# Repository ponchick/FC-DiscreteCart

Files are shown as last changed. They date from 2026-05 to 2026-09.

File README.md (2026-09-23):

# FC-DiscreteCart

Discrete logic Famicom / Dendy cartridge PCB.

The following board types are supported:  
NROM, CNROM, GNROM, BNROM, AMROM, ANROM, AOROM, UNROM, UOROM.

Russian version: [`README.ru.md`](README.ru.md)

## Jumper configuration

All jumpers except JP1 are set according to the table below.  
JP1 (VRAM_A10) selects PPU nametable mirroring — see the note after the table.

| ROM type | U1* type | U2 type | U3 74161 | U4 7432 | U5 7402 | JP1 VRAM_A10 | JP2 PRG_OE | JP3 CHR_PIN26 | JP4 CHR_PIN27 | JP5 161_Q2 | JP6 161_Q3 | JP7 PRG_A14 | JP8 PRG_A15 | JP9 PRG_A15 | JP10 PRG_A16 | JP11 PRG_A16 | JP12 PRG_A17 |
| :--- | :--- | :--- | --- | --- | --- | --- | --- | --- | --- | --- | --- | --- | --- | --- | --- | --- | --- |
| NROM | ROM 16kB/32kB | ROM 8kB | ✗ | ✗ | ✗ | V/H\*\* | bridge 2–3 | bridge 2–3 | bridge 2–4 | do not bridge | do not bridge | bridge 1–2 | do not bridge | bridge 2–3 | do not bridge | bridge 2–3 | bridge 2–4 |
| CNROM | ROM 16kB/32kB | ROM 32kB | ✓ | ✗ | ✗ | V/H\*\* | bridge 2–3 | bridge 1–2 | bridge 1–2 | bridge 1–2 | bridge 2–4 | bridge 1–2 | do not bridge | bridge 2–3 | do not bridge | bridge 2–3 | bridge 2–4 |
| GNROM | ROM 128kB | ROM 32kB | ✓ | ✗ | ✗ | V/H\*\* | bridge 2–3 | bridge 1–2 | bridge 1–2 | bridge 1–2 | bridge 2–4 | bridge 1–2 | do not bridge | bridge 1–2 | do not bridge | bridge 1–2 | bridge 2–4 |
| AMROM | ROM 128kB | RAM 8kB | ✓ | ✗ | ✗ | bridge 2–4 | bridge 2–3 | bridge 2–3 | bridge 2–3 | bridge 2–3 | bridge 2–3 | bridge 1–2 | bridge 2–3 | do not bridge | bridge 2–3 | do not bridge | bridge 2–3 |
| ANROM / AOROM | ROM 128kB/256kB | RAM 8kB | ✓ | ✗ | ✓ | bridge 2–4 | bridge 1–2 | bridge 2–3 | bridge 2–3 | bridge 2–3 | bridge 2–3 | bridge 1–2 | bridge 2–3 | do not bridge | bridge 2–3 | do not bridge | bridge 2–3 |
| BNROM | ROM 128kB | RAM 8kB | ✓ | ✗ | ✗ | V/H\*\* | bridge 2–3 | bridge 2–3 | bridge 2–3 | bridge 2–3 | bridge 2–3 | bridge 1–2 | bridge 2–3 | do not bridge | bridge 2–3 | do not bridge | bridge 2–3 |
| UxROM | ROM 128kB/256kB | RAM 8kB | ✓ | ✓ | ✗ | V/H\*\* | bridge 2–3 | bridge 2–3 | bridge 2–3 | bridge 2–3 | bridge 1–2 | bridge 2–3 | bridge 1–2 | do not bridge | bridge 1–2 | do not bridge | bridge 1–2 |

\* `U1`: for NROM/CNROM, ICs in `DIP-28` or `DIP-32` packages can be used.

\*\* JP1 (VRAM_A10) depends on the required PPU nametable mirroring:

| Mirroring | JP1 position |
| --- | --- |
| Vertical | bridge 1–2 |
| Horizontal | bridge 2–3 |

## License

This project is licensed under **CERN Open Hardware Licence Version 2 – Permissive** (`CERN-OHL-P-2.0`).  
See `LICENSE` for details.

SPDX-License-Identifier: `CERN-OHL-P-2.0`

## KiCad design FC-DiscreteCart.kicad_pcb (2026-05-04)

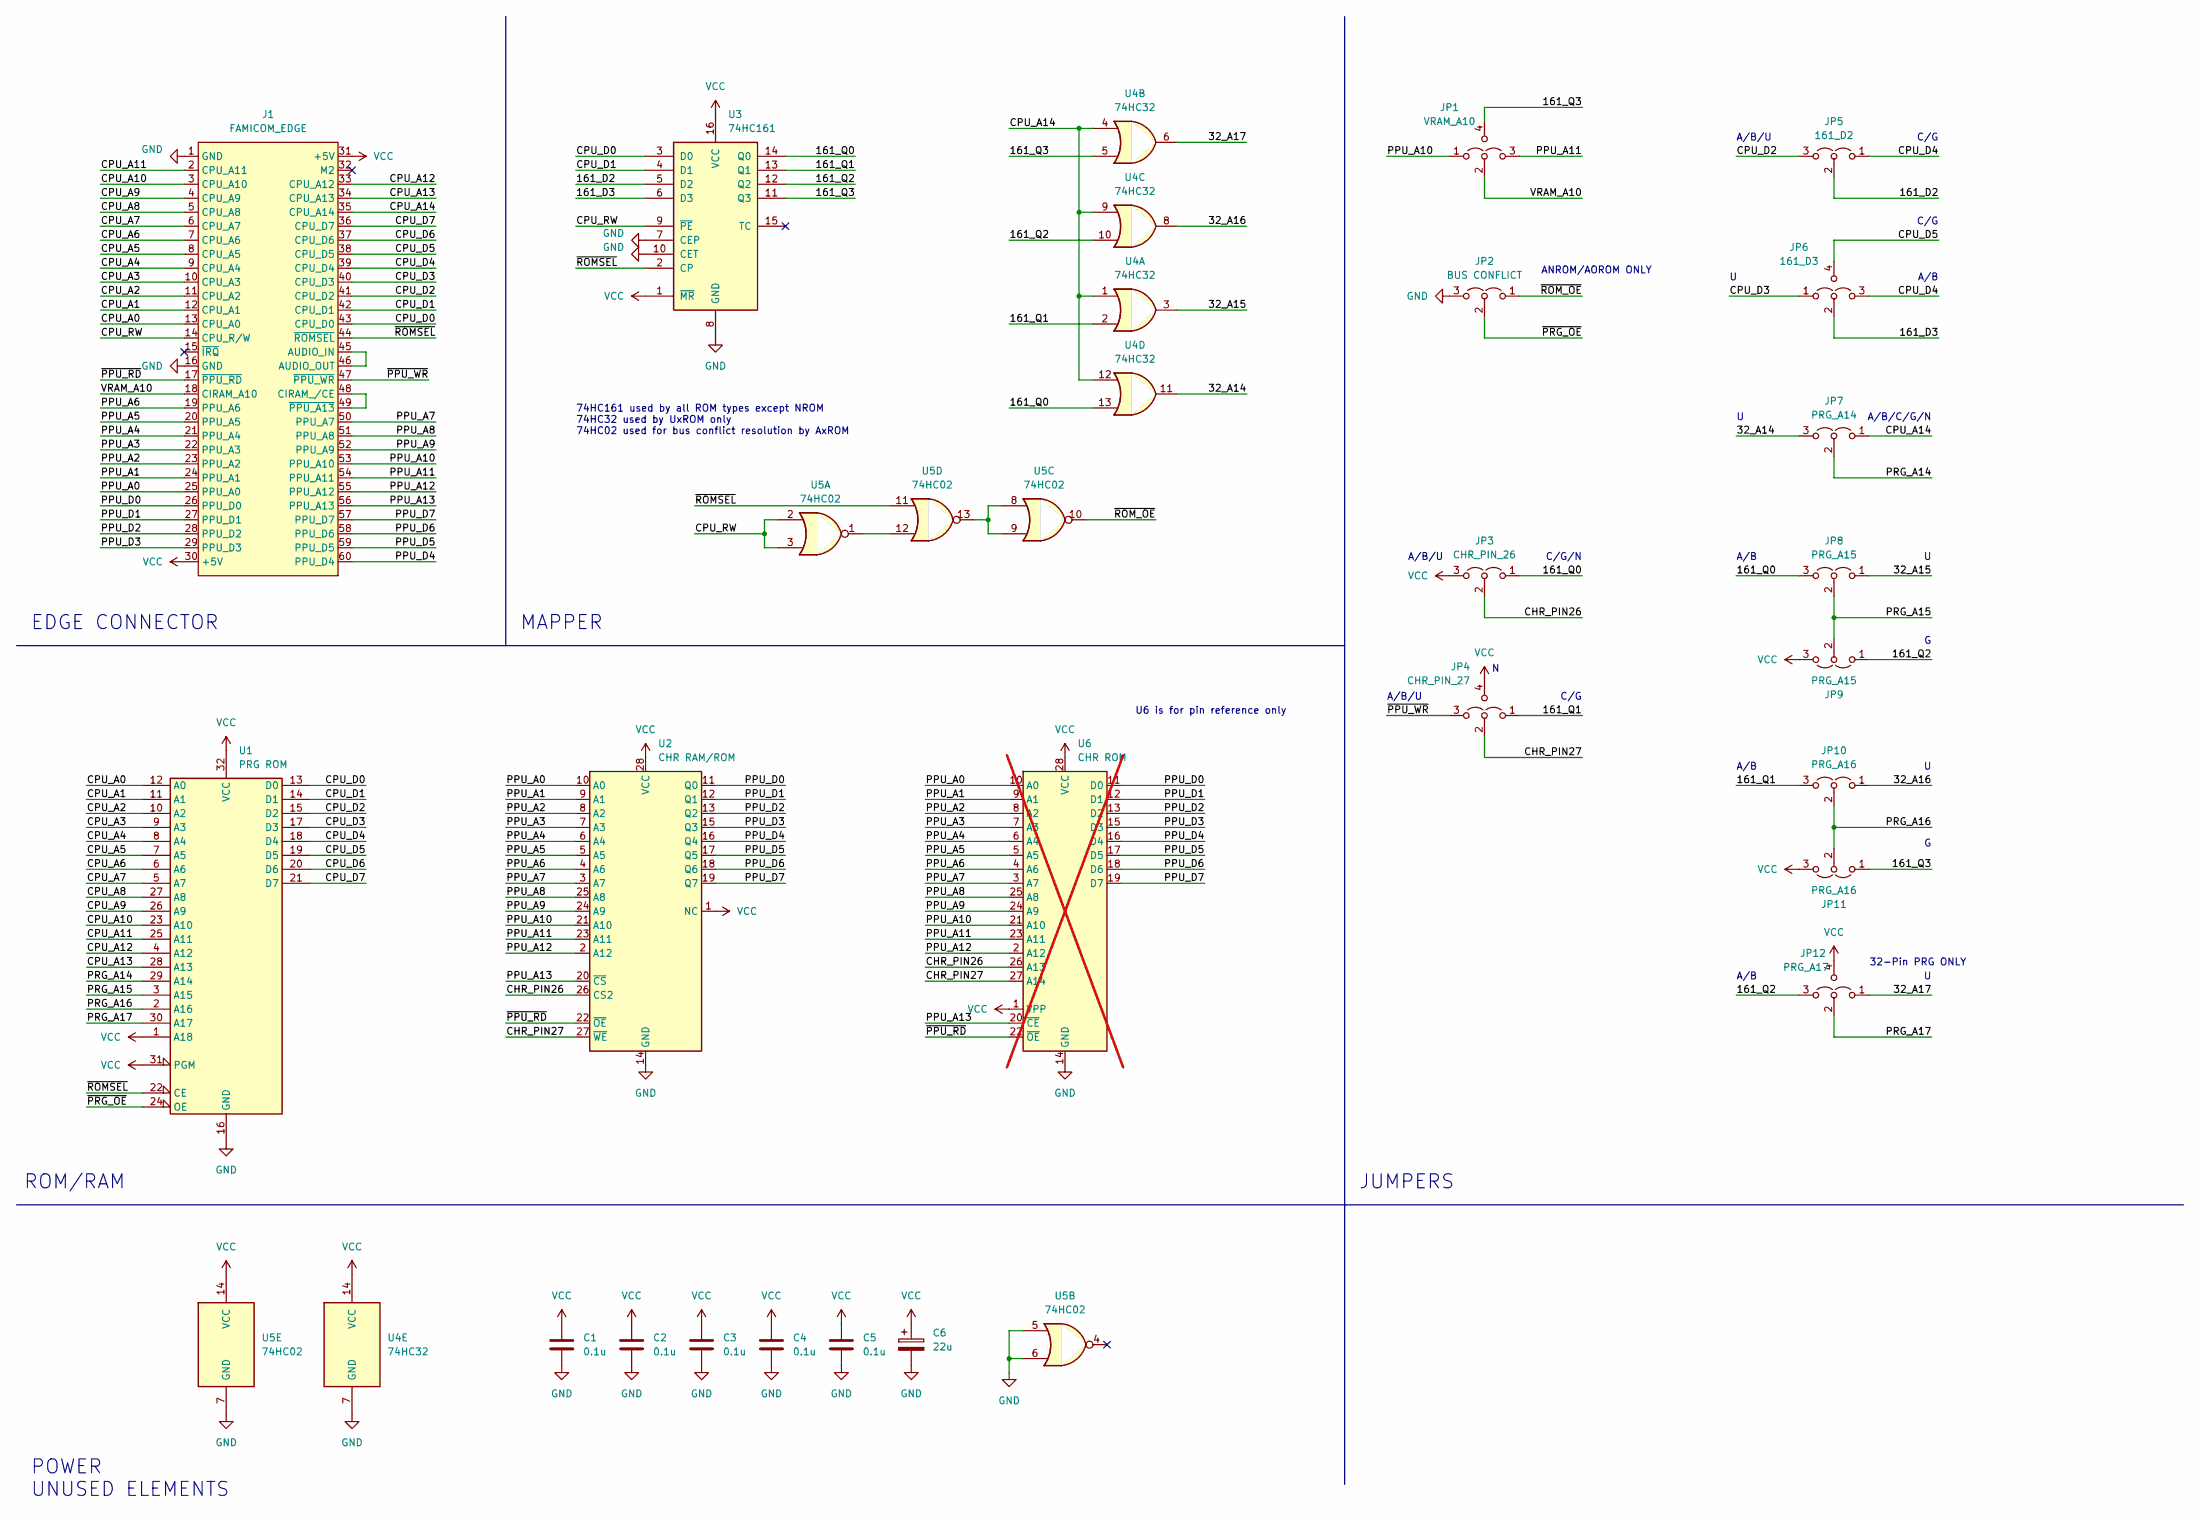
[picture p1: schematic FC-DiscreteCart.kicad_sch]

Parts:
C1, C2, C3, C4, C5: 0.1u; C_Disc_D4.3mm_W1.9mm_P5.00mm
C6: 22u; CP_Radial_D5.0mm_P2.50mm
J1: FAMICOM_EDGE; CONN_EDGE_2x60
JP1: VRAM_A10; SolderJumper-4
JP2: BUS CONFLICT; SolderJumper-3
JP3: CHR_PIN_26; SolderJumper-3
JP4: CHR_PIN_27; SolderJumper-4
JP5: 161_D2; SolderJumper-3
JP6: 161_D3; SolderJumper-4
JP7: PRG_A14; SolderJumper-3
JP8, JP9: PRG_A15; SolderJumper-3
JP10, JP11: PRG_A16; SolderJumper-3
JP12: PRG_A17; SolderJumper-4
U1: PRG ROM; DIP-32_W15.24mm_Socket
U2: CHR RAM/ROM; DIP-32_Triple
U3: 74HC161; DIP-16_W7.62mm
U4: 74HC32; DIP-14_W7.62mm
U5: 74HC02; DIP-14_W7.62mm
U6: CHR ROM; DIP-28_W15.24mm; not fitted

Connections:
/32_A14: JP7.3 (B), U4.11
/32_A15: JP8.1 (A), U4.3
/32_A16: JP10.1 (A), U4.8
/32_A17: JP12.1 (A), U4.6
/161_D2: JP5.2 (C), U3.5 (D2)
/161_D3: JP6.2 (C), U3.6 (D3)
/161_Q0: JP3.1 (A), JP8.3 (B), U3.14 (Q0), U4.13
/161_Q1: JP4.1 (A), JP10.3 (B), U3.13 (Q1), U4.2
/161_Q2: JP9.1 (A), JP12.3 (B), U3.12 (Q2), U4.10
/161_Q3: JP1.4 (B), JP11.1 (A), U3.11 (Q3), U4.5
/CHR_PIN26: JP3.2 (C), U2.26 (CS2), U4.26, U6.26 (A13)
/CHR_PIN27: JP4.2 (C), U2.27 (~WE), U4.27, U6.27 (A14)
/CPU_A0: J1.13 (CPU_A0), U1.12 (A0)
/CPU_A1: J1.12 (CPU_A1), U1.11 (A1)
/CPU_A2: J1.11 (CPU_A2), U1.10 (A2)
/CPU_A3: J1.10 (CPU_A3), U1.9 (A3)
/CPU_A4: J1.9 (CPU_A4), U1.8 (A4)
/CPU_A5: J1.8 (CPU_A5), U1.7 (A5)
/CPU_A6: J1.7 (CPU_A6), U1.6 (A6)
/CPU_A7: J1.6 (CPU_A7), U1.5 (A7)
/CPU_A8: J1.5 (CPU_A8), U1.27 (A8)
/CPU_A9: J1.4 (CPU_A9), U1.26 (A9)
/CPU_A10: J1.3 (CPU_A10), U1.23 (A10)
/CPU_A11: J1.2 (CPU_A11), U1.25 (A11)
/CPU_A12: J1.33 (CPU_A12), U1.4 (A12)
/CPU_A13: J1.34 (CPU_A13), U1.28 (A13)
/CPU_A14: J1.35 (CPU_A14), JP7.1 (A), U4.1, U4.4, U4.9, U4.12
/CPU_D0: J1.43 (CPU_D0), U1.13 (D0), U3.3 (D0)
/CPU_D1: J1.42 (CPU_D1), U1.14 (D1), U3.4 (D1)
/CPU_D2: J1.41 (CPU_D2), JP5.3 (B), U1.15 (D2)
/CPU_D3: J1.40 (CPU_D3), JP6.1 (A), U1.17 (D3)
/CPU_D4: J1.39 (CPU_D4), JP5.1 (A), JP6.3 (B), U1.18 (D4)
/CPU_D5: J1.38 (CPU_D5), JP6.4 (B), U1.19 (D5)
/CPU_D6: J1.37 (CPU_D6), U1.20 (D6)
/CPU_D7: J1.36 (CPU_D7), U1.21 (D7)
/CPU_RW: J1.14 (CPU_R/W), U3.9 (~PE), U5.2, U5.3
/PPU_A0: J1.25 (PPU_A0), U2.10 (A0)
/PPU_A1: J1.24 (PPU_A1), U2.9 (A1)
/PPU_A2: J1.23 (PPU_A2), U2.8 (A2)
/PPU_A3: J1.22 (PPU_A3), U2.7 (A3)
/PPU_A4: J1.21 (PPU_A4), U2.6 (A4)
/PPU_A5: J1.20 (PPU_A5), U2.5 (A5)
/PPU_A6: J1.19 (PPU_A6), U2.4 (A6)
/PPU_A7: J1.50 (PPU_A7), U2.3 (A7)
/PPU_A8: J1.51 (PPU_A8), U2.25 (A8), U4.25, U6.25 (A8)
/PPU_A9: J1.52 (PPU_A9), U2.24 (A9), U4.24, U6.24 (A9)
/PPU_A10: J1.53 (PPU_A10), JP1.1 (A), U2.21 (A10), U4.21, U6.21 (A10)
/PPU_A11: J1.54 (PPU_A11), JP1.3 (B), U2.23 (A11), U4.23, U6.23 (A11)
/PPU_A12: J1.55 (PPU_A12), U2.2 (A12)
/PPU_A13: J1.56 (PPU_A13), U2.20 (~CS), U4.20, U6.20 (~CE)
/PPU_D0: J1.26 (PPU_D0), U2.11 (Q0)
/PPU_D1: J1.27 (PPU_D1), U2.12 (Q1)
/PPU_D2: J1.28 (PPU_D2), U2.13 (Q2)
/PPU_D3: J1.29 (PPU_D3), U2.15 (Q3), U4.15, U6.15 (D3)
/PPU_D4: J1.60 (PPU_D4), U2.16 (Q4), U4.16, U6.16 (D4)
/PPU_D5: J1.59 (PPU_D5), U2.17 (Q5), U4.17, U6.17 (D5)
/PPU_D6: J1.58 (PPU_D6), U2.18 (Q6), U4.18, U6.18 (D6)
/PPU_D7: J1.57 (PPU_D7), U2.19 (Q7), U4.19, U6.19 (D7)
/PRG_A14: JP7.2 (C), U1.29 (A14)
/PRG_A15: JP8.2 (C), JP9.2 (C), U1.3 (A15)
/PRG_A16: JP10.2 (C), JP11.2 (C), U1.2 (A16)
/PRG_A17: JP12.2 (C), U1.30 (A17)
/VRAM_A10: J1.18 (CIRAM_A10), JP1.2 (C)
/~PPU_RD: J1.17 (~PPU_RD), U2.22 (~OE), U4.22, U6.22 (~OE)
/~PPU_WR: J1.47 (~PPU_WR), JP4.3 (B)
/~PRG_OE: JP2.2 (C), U1.24 (OE)
/~ROMSEL: J1.44 (~ROMSEL), U1.22 (CE), U3.2 (CP), U5.11
/~ROM_OE: JP2.1 (A), U5.10
GND: C1.2, C2.2, C3.2, C4.2, C5.2, C6.2, J1.1 (GND), J1.16 (GND), JP2.3 (B), U1.16 (GND), U2.14 (GND), U3.7 (CEP), U3.8 (GND), U3.10 (CET), U4.7 (GND), U5.5, U5.6, U5.7 (GND)
unnamed: J1.45 (AUDIO_IN), J1.46 (AUDIO_OUT)
unnamed: J1.48 (CIRAM_/CE), J1.49 (~PPU_A13)
unnamed: U5.1, U5.12
unnamed: U5.8, U5.9, U5.13
VCC: C1.1, C2.1, C3.1, C4.1, C5.1, C6.1, J1.30 (+5V), J1.31 (+5V), JP3.3 (B), JP4.4 (B), JP9.3 (B), JP11.3 (B), JP12.4 (B), U1.1 (A18), U1.31 (PGM), U1.32 (VCC), U2.1 (NC), U2.28 (VCC), U3.1 (~MR), U3.16 (VCC), U4.14 (VCC), U5.14 (VCC)

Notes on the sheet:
C/G
MAPPER
A/B/C/G/N
ANROM/AOROM ONLY
ROM/RAM
A/B
74HC161 used by all ROM types except NROM 74HC32 used by UxROM only 74HC02 used for bus conflict resolution by AxROM
A/B/U
JUMPERS
U6 is for pin reference only
32-Pin PRG ONLY
C/G/N
EDGE CONNECTOR
POWER UNUSED ELEMENTS

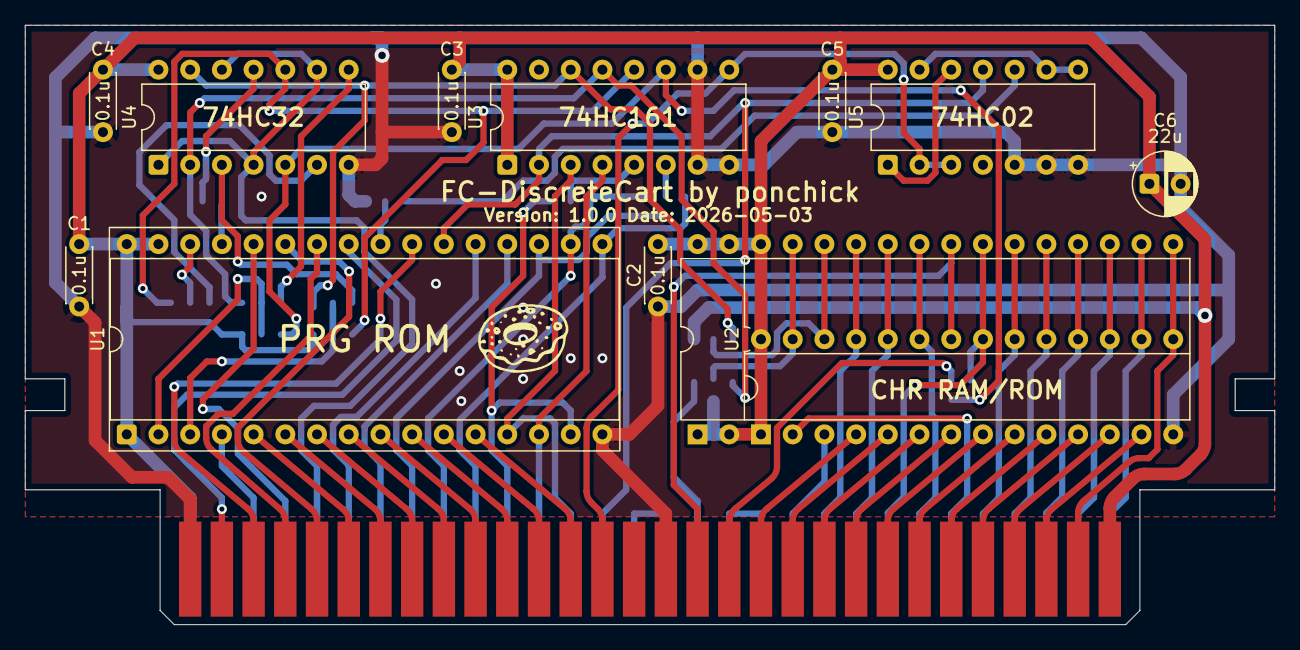
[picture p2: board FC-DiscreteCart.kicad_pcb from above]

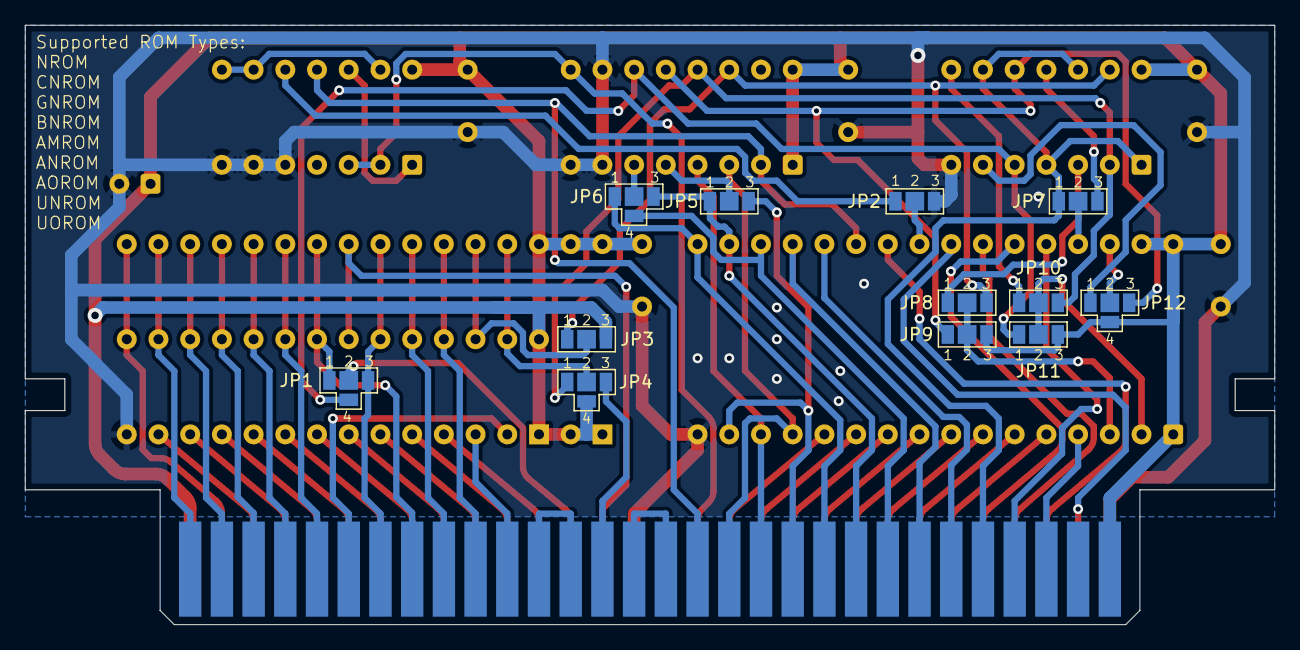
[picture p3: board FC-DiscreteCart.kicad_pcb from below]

Board: 2 copper layers, 100.1 x 48.0 mm, 25 parts (12 on the bottom side), 74 nets.

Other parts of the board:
LOGO#: LOGO; ponchick

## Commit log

2026-05-06 Update README files to clarify PCB compatibility and jumper settings for Famicom/Dendy cartridges
2026-06-20 Fix image references in Jumpers.html and update README files for consistency in PCB compatibility and jumper settings.
